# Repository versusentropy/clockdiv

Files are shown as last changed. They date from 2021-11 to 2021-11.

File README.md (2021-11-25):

# eurorack clockdivider

## v0.3 this version is not yet tested!

## Classic CD4024 7 step binary clock-divider

  * 6hp
  * +/-12V 20mA/-
  * 1 PCB 2 layer
    * 73 parts total
    * 14 SMT, 4 THT
  * +5V gate outputs
  * clock input
    * TN pin header on pcb
  * reset input
    * 2nd pin header on pcb
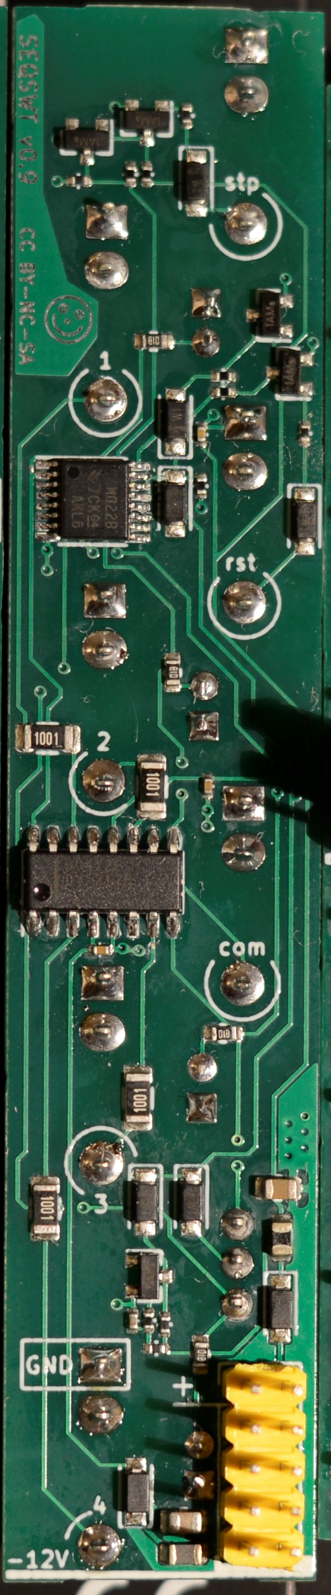
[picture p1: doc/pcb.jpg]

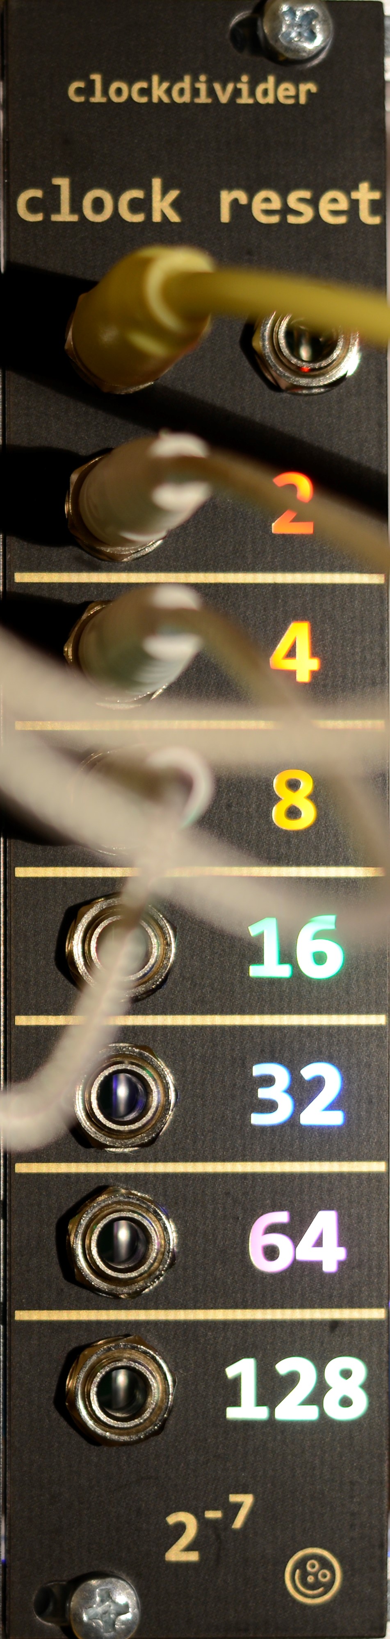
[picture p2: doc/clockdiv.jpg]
panel

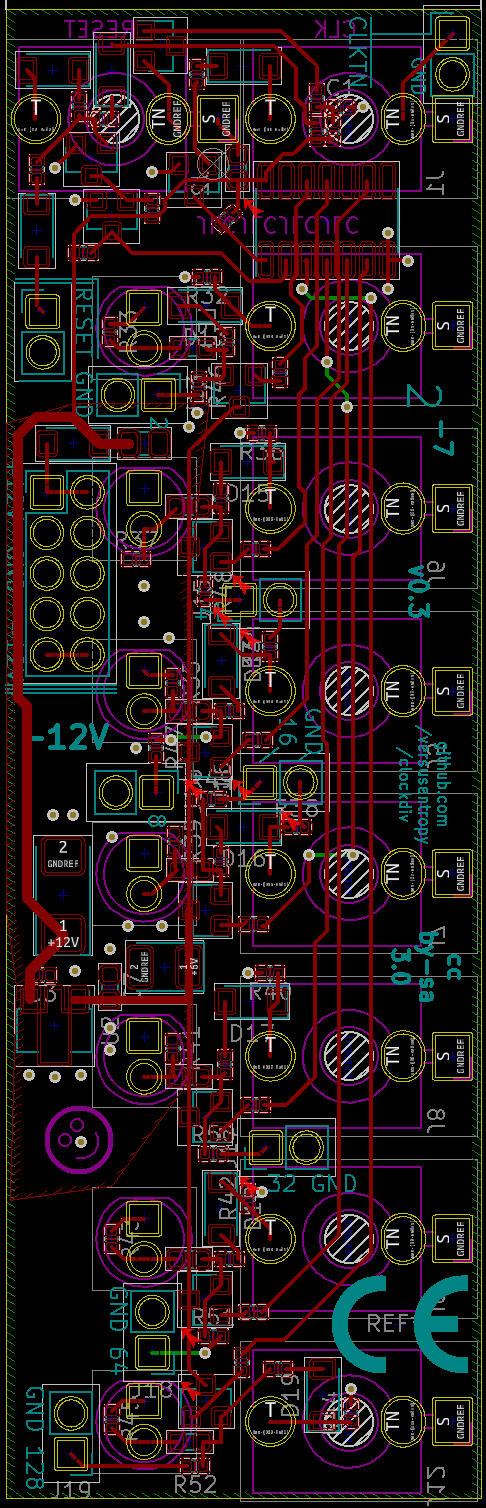
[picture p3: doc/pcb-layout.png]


Schematic and layout with KiCad 5. Panel with Inkscape + shenzen2svg → Kicad

Ordered mine at JLCPCB. Gerbers include marking for order number. BOM with part numbers for their assembly service.

Be carful with the transisors' pin numbers, because the 2N3904 schematic symbol doesn't match the MMBT3904 part (, which has its own schematic symbol). 

divider
The CLK input is buffered and inverted by Q2.

The RESET input (and the additional pin-header) are buffered by Q3 & Q4. Q1 resets the clockdivider at startup, until C1 is charged up.

output
A MMBT3904 buffers each output and its LED. The jack is protected by a diode and a 1k resistor. So multiple jacks can be combined.

On the back pin headers allow connections to other modules (not prtected by diodes, but a 1k resistor).

power
L78L06 to power everything else with 6.0V.

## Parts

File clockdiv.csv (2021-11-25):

Comment | Designator | Footprint | LCSC
1u | C1 | Capacitor_SMD:C_0402_1005Metric | C52923
330n | C3 | Capacitor_SMD:C_0402_1005Metric | C13533
22u | C4 | Capacitor_SMD:C_0805_2012Metric | C45783
10u | C5 | Capacitor_Tantalum_SMD:CP_EIA-6032-28_Kemet-C | C116748
22u | C6 | Capacitor_Tantalum_SMD:CP_EIA-3528-21_Kemet-B | C8020
100n | C2,C7 | Capacitor_SMD:C_0603_1608Metric | C14663
1N4148 | D1,D2,D3,D4,D5,D13,D14,D15,D16,D17,D18,D19 | Diode_SMD:D_SOD-123 | C81598
LED | D6,D7,D8,D9,D10,D11,D12 | LED_THT:LED_D5.0mm
CLK | J1 | kicad_jacks:Jack_3.5mm_QingPu_WQP-PJ398SM_Vertical_CircularHolesSMALL
CLKTN GND | J10 | Connector_PinHeader_2.54mm:PinHeader_1x02_P2.54mm_Vertical
+12V GND -12V | J11 | Connector_PinHeader_2.54mm:PinHeader_2x05_P2.54mm_Vertical
GND | J13,J14,J15,J16,J17,J18,J19 | Connector_PinHeader_2.54mm:PinHeader_1x02_P2.54mm_Vertical
RESET | J2 | kicad_jacks:Jack_3.5mm_QingPu_WQP-PJ398SM_Vertical_CircularHolesSMALL
RESET GND | J3 | Connector_PinHeader_2.54mm:PinHeader_1x02_P2.54mm_Vertical
OUT | J4,J5,J6,J7,J8,J9,J12 | kicad_jacks:Jack_3.5mm_QingPu_WQP-PJ398SM_Vertical_CircularHolesSMALL
2N3904 | Q1,Q2,Q3,Q4,Q5,Q6,Q7,Q8,Q9,Q10,Q11 | Package_TO_SOT_SMD:SOT-23 | C20526
100k | R1,R10,R13,R16,R19,R22,R25,R28 | Resistor_SMD:R_0402_1005Metric | C25741
1k | R12,R14,R17,R20,R23,R26,R29,R46,R47,R48,R49,R50,R51,R52 | Resistor_SMD:R_0402_1005Metric | C11702
470 | R15,R18,R21,R24,R27,R30,R31 | Resistor_SMD:R_0603_1608Metric | C23179
1M | R32,R33,R34,R35,R36,R37,R38,R39,R40,R41,R42,R43,R44,R45 | Resistor_SMD:R_0402_1005Metric | C26083
47k | R4,R5,R6,R7 | Resistor_SMD:R_0402_1005Metric | C25792
10k | R2,R3,R8,R9,R11 | Resistor_SMD:R_0402_1005Metric | C25744
4024 | U1 | Package_SO:SOIC-14_3.9x8.7mm_P1.27mm | C157535
L78L06_SOT89 | U2 | Package_TO_SOT_SMD:SOT-89-3 | C347269

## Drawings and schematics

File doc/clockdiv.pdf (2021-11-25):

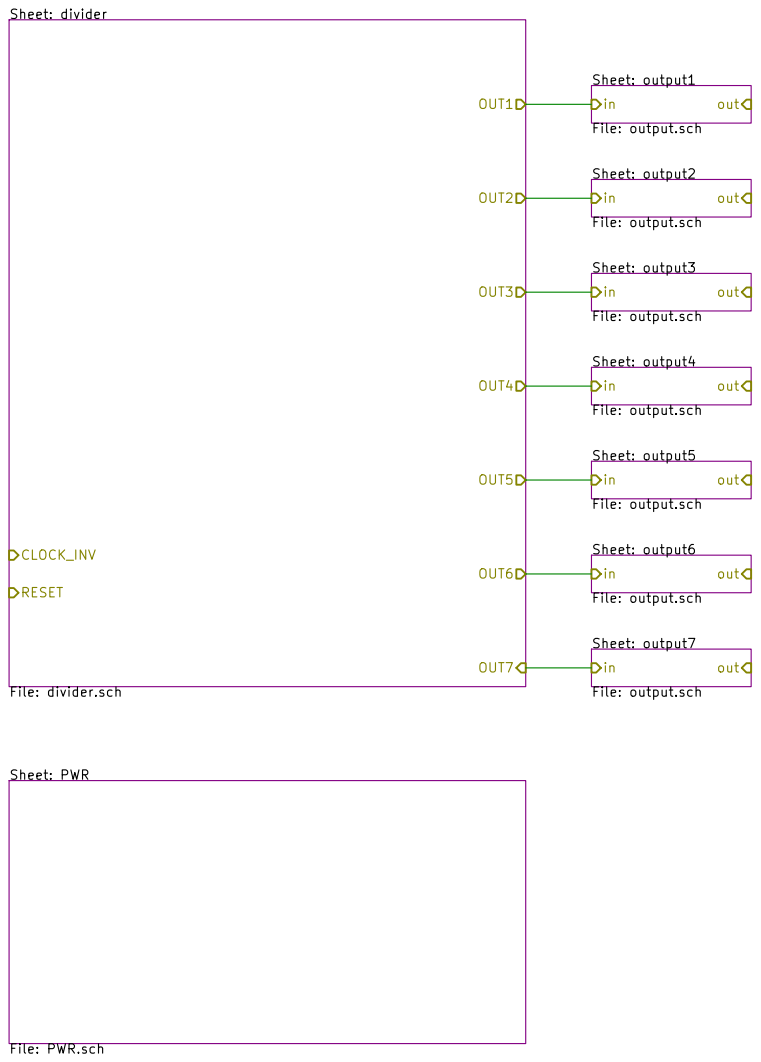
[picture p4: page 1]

Id: 1/10 Title: File: clockdiv.sch Sheet: / Sheet: PWR

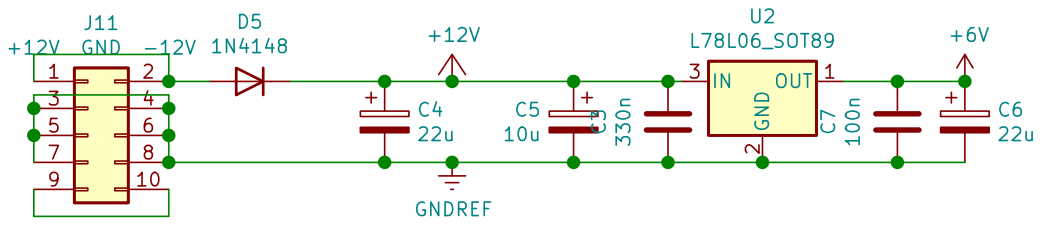
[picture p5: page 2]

Id: 2/10 Title: File: PWR.sch Sheet: /PWR/

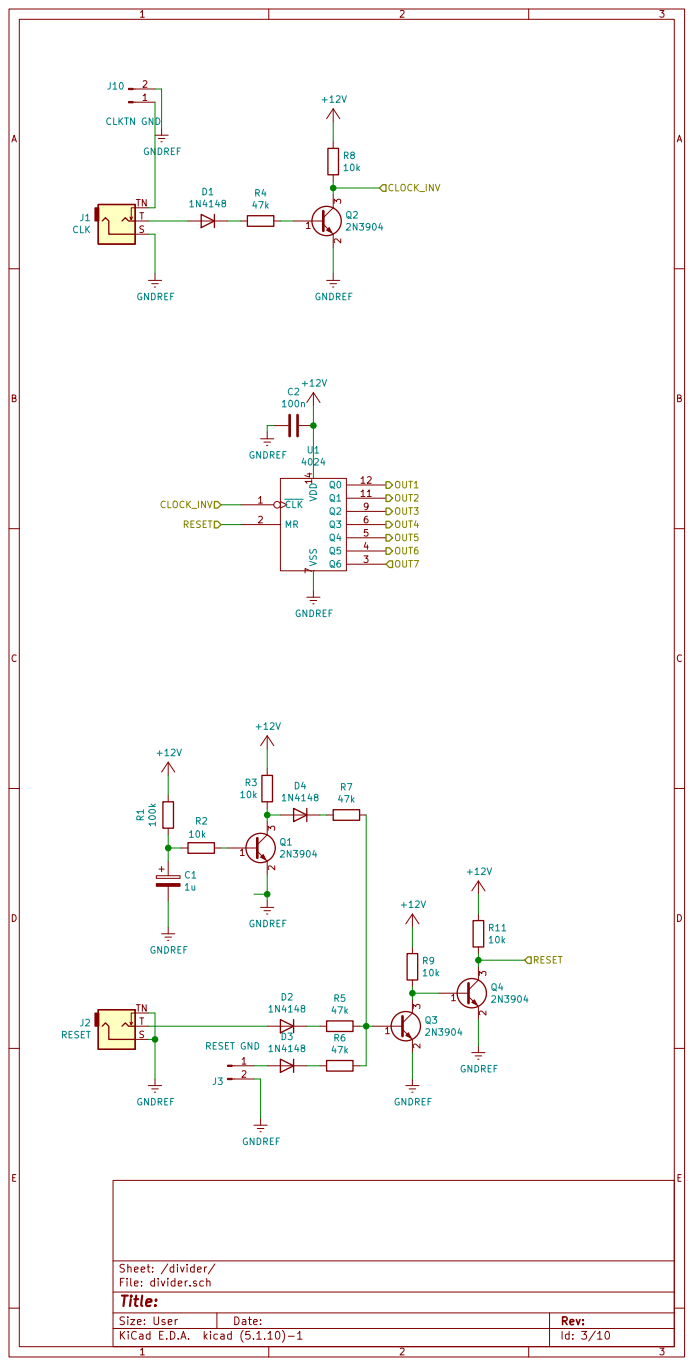
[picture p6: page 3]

Id: 3/10 Title: File: divider.sch Sheet: /divider/

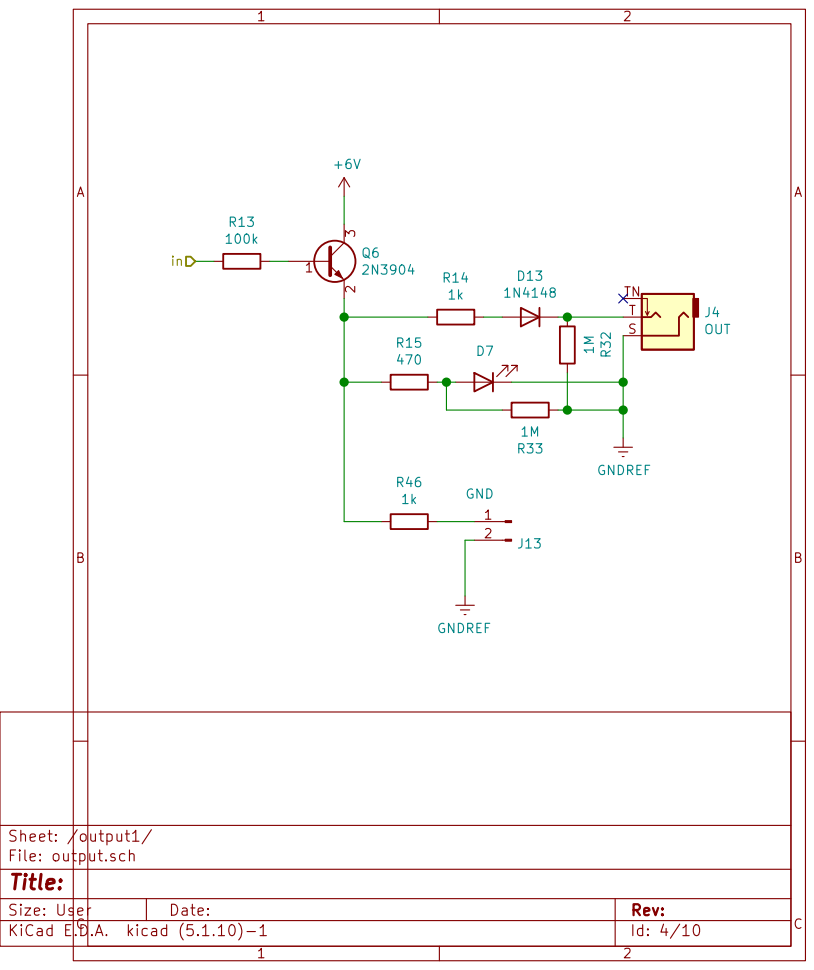
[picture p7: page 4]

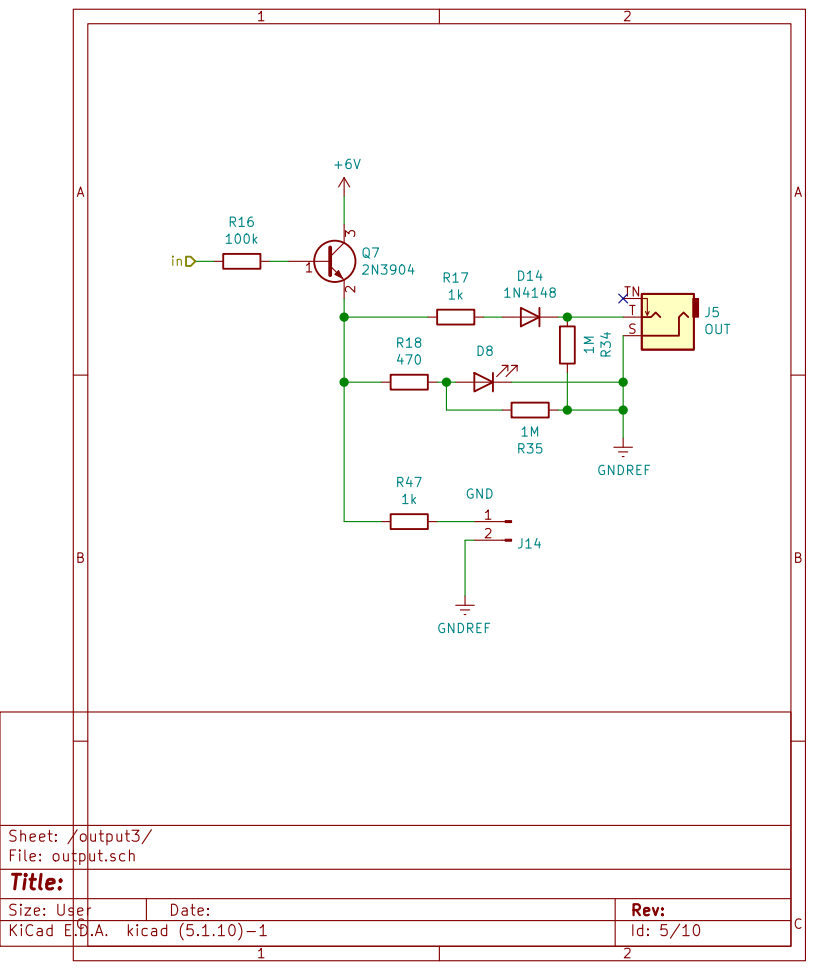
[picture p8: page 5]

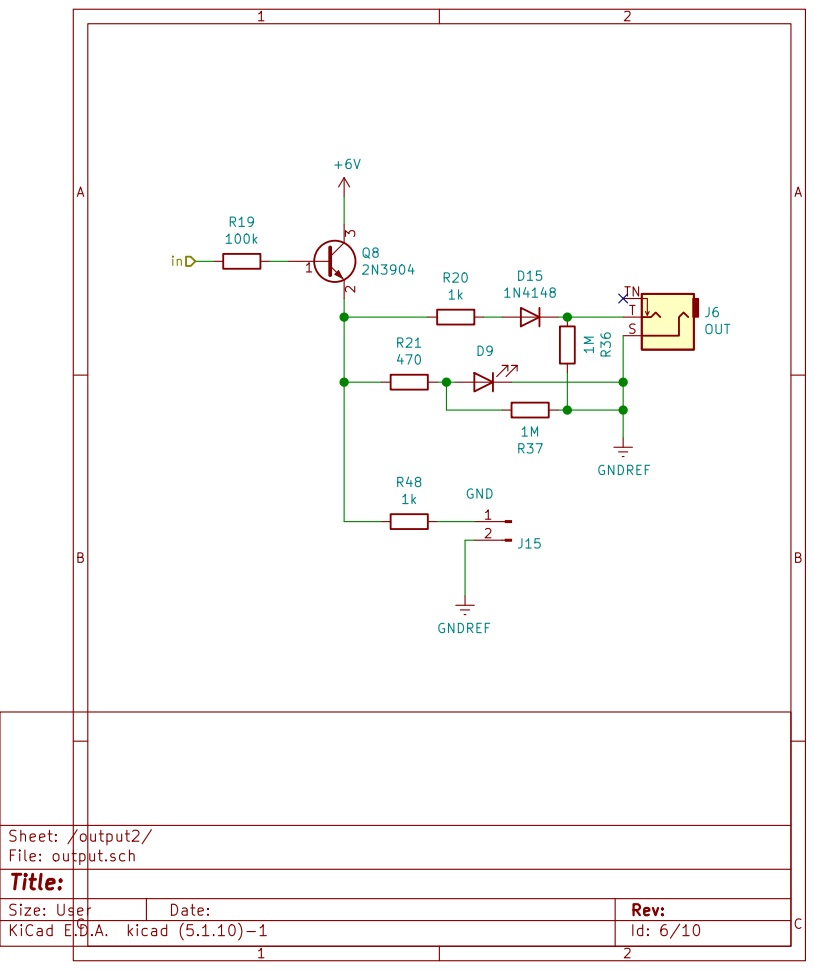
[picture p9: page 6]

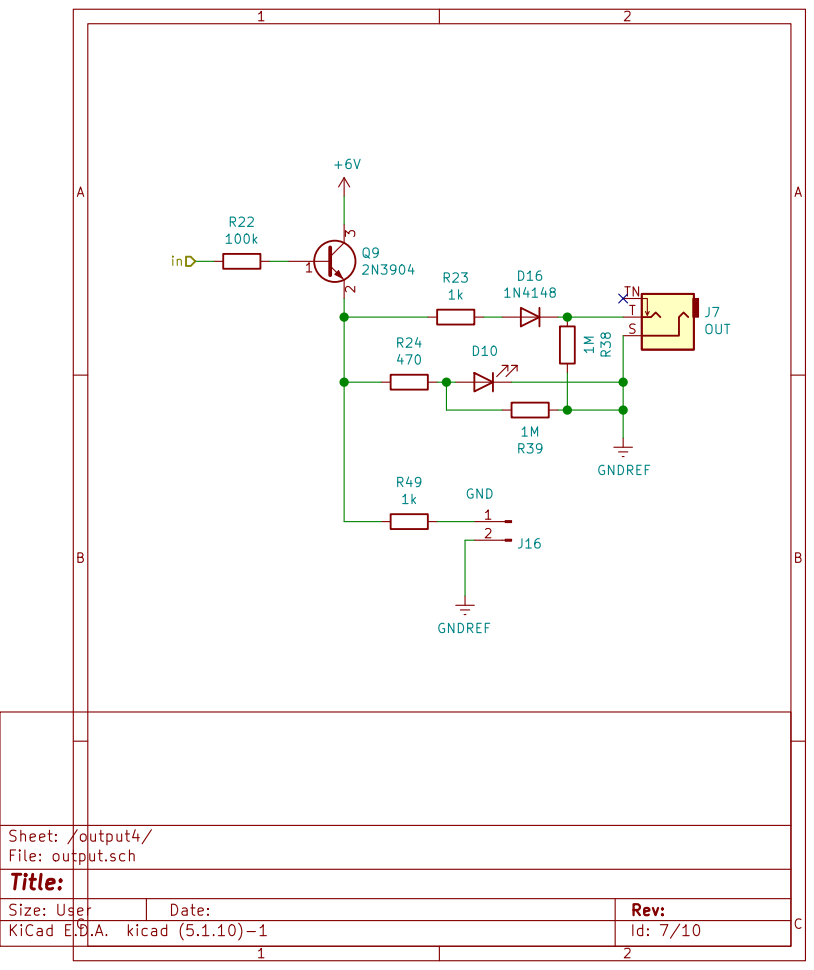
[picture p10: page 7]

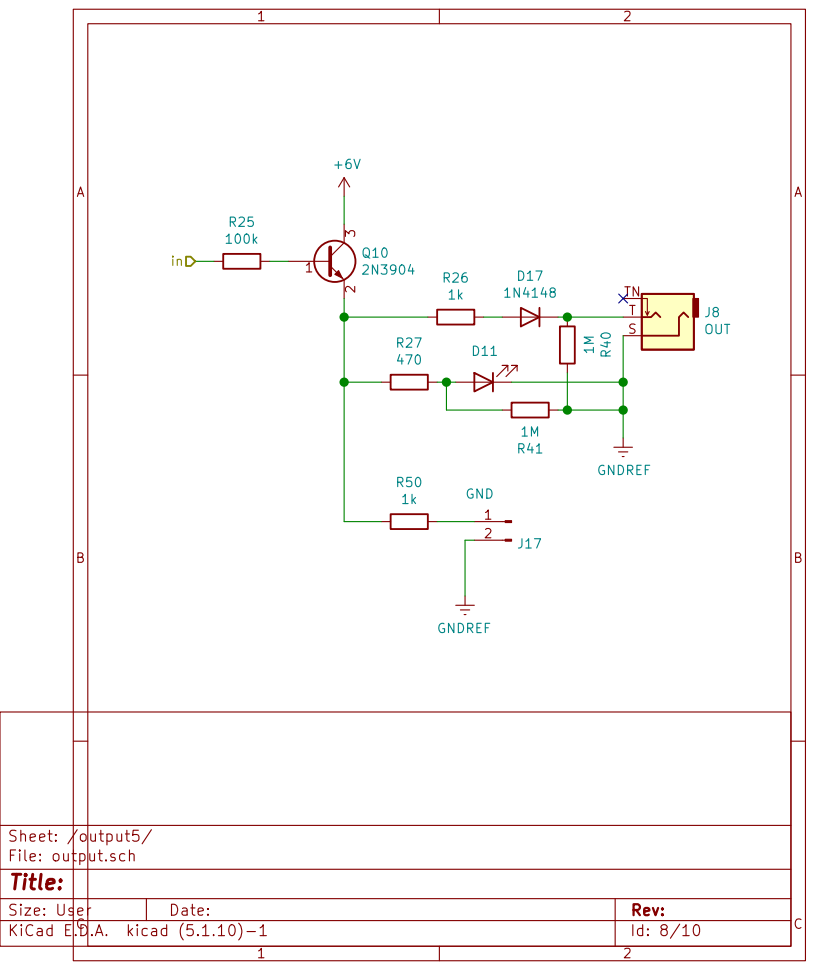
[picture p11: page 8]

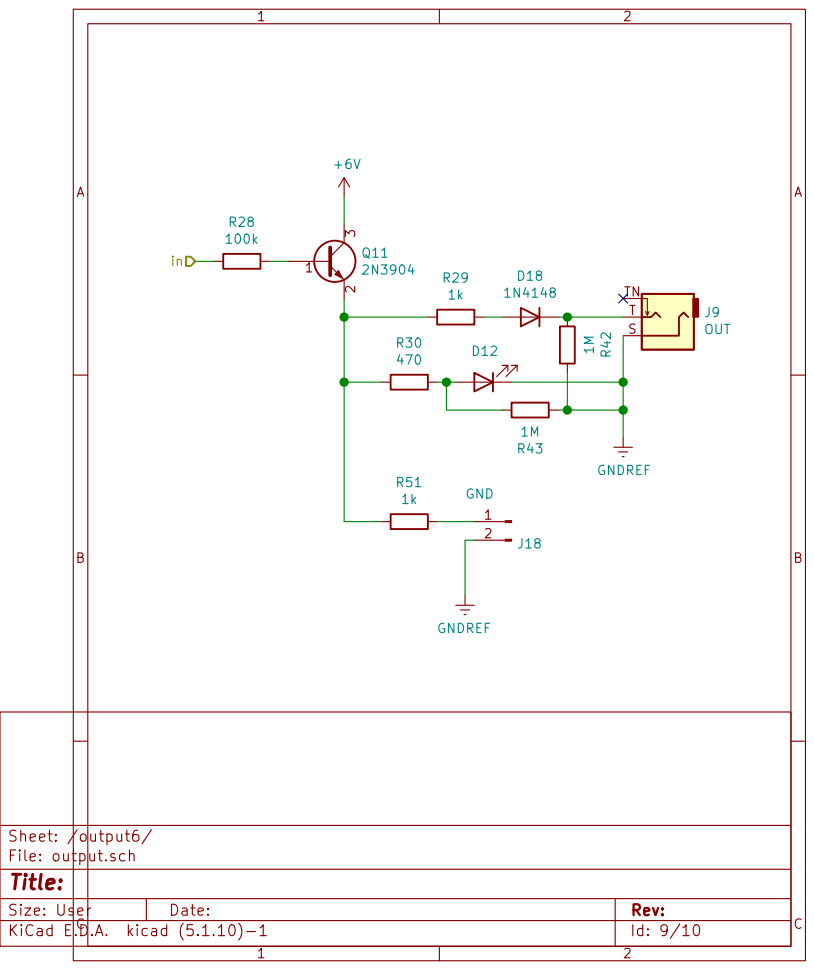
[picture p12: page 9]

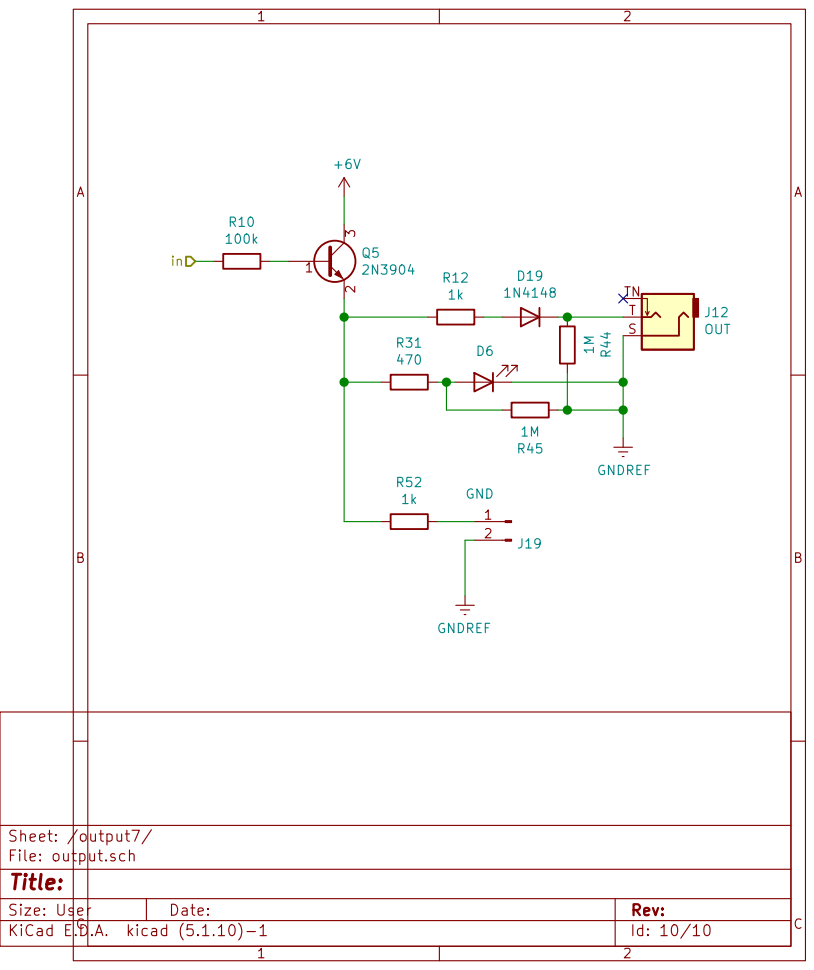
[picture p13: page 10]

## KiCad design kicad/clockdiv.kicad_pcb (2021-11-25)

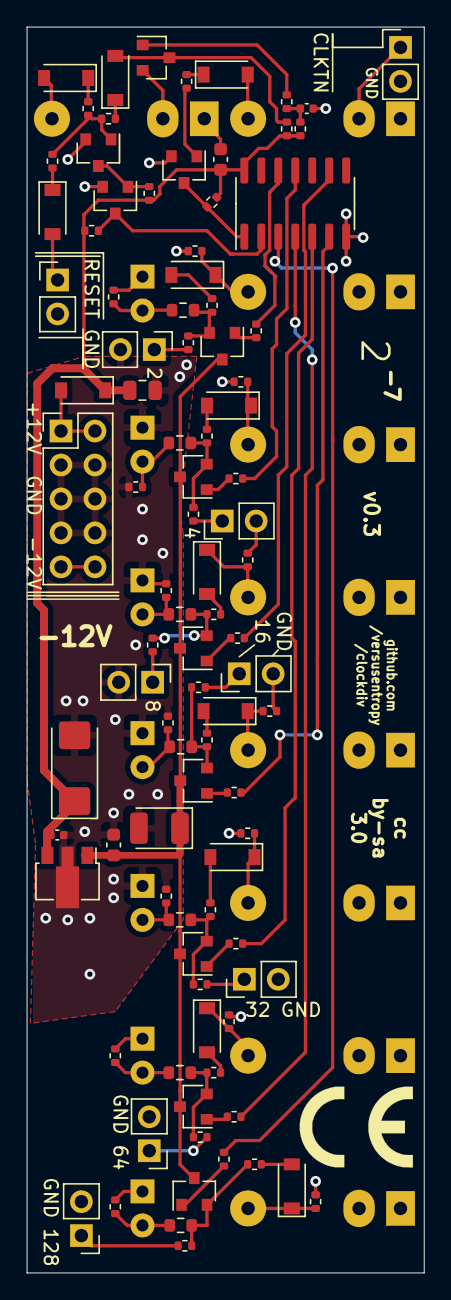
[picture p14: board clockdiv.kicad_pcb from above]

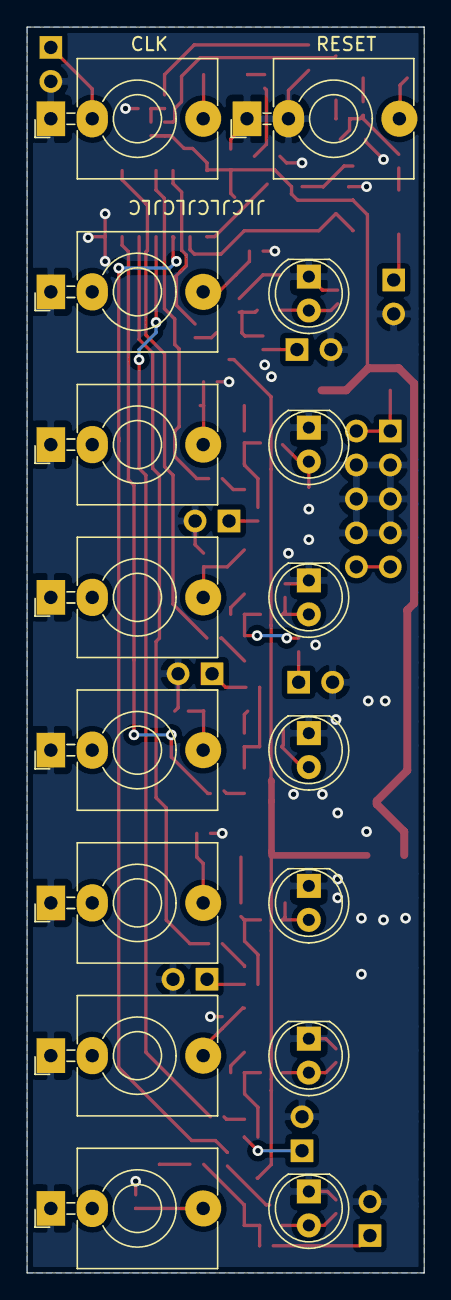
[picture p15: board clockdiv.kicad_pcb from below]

Board: 2 copper layers, 29.7 x 93.2 mm, 110 parts (16 on the bottom side), 70 nets.

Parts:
C1: 1u; C_0402_1005Metric
C2, C7: 100n; C_0603_1608Metric
C3: 330n; C_0402_1005Metric
C4: 22u; C_0805_2012Metric
C5: 10u; CP_EIA-6032-28_Kemet-C
C6: 22u; CP_EIA-3528-21_Kemet-B
D1, D2, D3, D4, D5, D13, D14, D15, D16, D17, D18, D19: 1N4148; D_SOD-123
D6, D7, D8, D9, D10, D11, D12: LED; LED_D5.0mm
J1: CLK; Jack_3.5mm_QingPu_WQP-PJ398SM_Vertical_CircularHolesSMALL
J2: RESET; Jack_3.5mm_QingPu_WQP-PJ398SM_Vertical_CircularHolesSMALL
J3: RESET GND; PinHeader_1x02_P2.54mm_Vertical
J4, J5, J6, J7, J8, J9, J12: OUT; Jack_3.5mm_QingPu_WQP-PJ398SM_Vertical_CircularHolesSMALL
J10: CLKTN GND; PinHeader_1x02_P2.54mm_Vertical
J11: +12V GND -12V; PinHeader_2x05_P2.54mm_Vertical
J13, J14, J15, J16, J17, J18, J19: GND; PinHeader_1x02_P2.54mm_Vertical
Q1, Q2, Q3, Q4, Q5, Q6, Q7, Q8, Q9, Q10, Q11: 2N3904; SOT-23
R1, R10, R13, R16, R19, R22, R25, R28: 100k; R_0402_1005Metric
R2, R3, R8, R9, R11: 10k; R_0402_1005Metric
R4, R5, R6, R7: 47k; R_0402_1005Metric
R12, R14, R17, R20, R23, R26, R29, R46, R47, R48, R49, R50, R51, R52: 1k; R_0402_1005Metric
R15, R18, R21, R24, R27, R30, R31: 470; R_0603_1608Metric
R32, R33, R34, R35, R36, R37, R38, R39, R40, R41, R42, R43, R44, R45: 1M; R_0402_1005Metric
U1: 4024; SOIC-14_3.9x8.7mm_P1.27mm
U2: L78L06_SOT89; SOT-89-3

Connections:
+6V: C6.1, C7.2, Q5.3, Q6.3, Q7.3, Q8.3, Q9.3, Q10.3, Q11.3, U2.1
+12V: C2.2, C3.2, C4.1, C5.1, D5.1, R1.2, R3.1, R8.1, R9.1, R11.1, U1.14, U2.3
/divider/CLOCK_INV: Q2.3, R8.2, U1.1
/divider/OUT1: R13.1, U1.12
/divider/OUT2: R19.1, U1.11
/divider/OUT3: R16.1, U1.9
/divider/OUT4: R22.1, U1.6
/divider/OUT5: R25.1, U1.5
/divider/OUT6: R28.1, U1.4
/divider/OUT7: R10.1, U1.3
/divider/RESET: Q4.3, R11.2, U1.2
GNDREF: C1.2, C2.1, C3.1, C4.2, C5.2, C6.2, C7.1, D6.1, D7.1, D8.1, D9.1, D10.1, D11.1, D12.1, J1.S, J2.S, J2.TN, J3.2, J4.S, J5.S, J6.S, J7.S, J8.S, J9.S, J10.2, J11.3, J11.4, J11.5, J11.6, J11.7, J11.8, J12.S, J13.2, J14.2, J15.2, J16.2, J17.2, J18.2, J19.2, Q1.2, Q2.2, Q3.2, Q4.2, R32.2, R33.1, R34.2, R35.1, R36.2, R37.1, R38.2, R39.1, R40.2, R41.1, R42.2, R43.1, R44.2, R45.1, U1.7, U2.2
unnamed: C1.1, R1.1, R2.2
unnamed: D1.1, R4.1
unnamed: D1.2, J1.T
unnamed: D2.1, R5.1
unnamed: D2.2, J2.T
unnamed: D3.1, R6.1
unnamed: D3.2, J3.1
unnamed: D4.1, R7.1
unnamed: D4.2, Q1.3, R3.2
unnamed: D5.2, J11.1, J11.2
unnamed: D6.2, R31.2, R45.2
unnamed: D7.2, R15.2, R33.2
unnamed: D8.2, R18.2, R35.2
unnamed: D9.2, R21.2, R37.2
unnamed: D10.2, R24.2, R39.2
unnamed: D11.2, R27.2, R41.2
unnamed: D12.2, R30.2, R43.2
unnamed: D13.1, J4.T, R32.1
unnamed: D13.2, R14.2
unnamed: D14.1, J5.T, R34.1
unnamed: D14.2, R17.2
unnamed: D15.1, J6.T, R36.1
unnamed: D15.2, R20.2
unnamed: D16.1, J7.T, R38.1
unnamed: D16.2, R23.2
unnamed: D17.1, J8.T, R40.1
unnamed: D17.2, R26.2
unnamed: D18.1, J9.T, R42.1
unnamed: D18.2, R29.2
unnamed: D19.1, J12.T, R44.1
unnamed: D19.2, R12.2
unnamed: J1.TN, J10.1
unnamed: J11.9, J11.10
unnamed: J13.1, R46.2
unnamed: J14.1, R47.2
unnamed: J15.1, R48.2
unnamed: J16.1, R49.2
unnamed: J17.1, R50.2
unnamed: J18.1, R51.2
unnamed: J19.1, R52.2
unnamed: Q1.1, R2.1
unnamed: Q2.1, R4.2
unnamed: Q3.1, R5.2, R6.2, R7.2
unnamed: Q3.3, Q4.1, R9.2
unnamed: Q5.1, R10.2
unnamed: Q5.2, R12.1, R31.1, R52.1
unnamed: Q6.1, R13.2
unnamed: Q6.2, R14.1, R15.1, R46.1
unnamed: Q7.1, R16.2
unnamed: Q7.2, R17.1, R18.1, R47.1
unnamed: Q8.1, R19.2
unnamed: Q8.2, R20.1, R21.1, R48.1
unnamed: Q9.1, R22.2
unnamed: Q9.2, R23.1, R24.1, R49.1
unnamed: Q10.1, R25.2
unnamed: Q10.2, R26.1, R27.1, R50.1
unnamed: Q11.1, R28.2
unnamed: Q11.2, R29.1, R30.1, R51.1

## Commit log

2021-11-05 cut SVGs
2021-11-05 resisze pcb
2021-11-25 Use 6V. Add output diodes + output pin headers
    [PWR.sch, clockdiv.kicad_pcb, divider.sch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]
2021-11-25 gerbers for v0.3 + BOM+POS + doc
    [clockdiv-B_Cu.gbl, clockdiv-B_Mask.gbs, clockdiv-B_Paste.gbp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]
